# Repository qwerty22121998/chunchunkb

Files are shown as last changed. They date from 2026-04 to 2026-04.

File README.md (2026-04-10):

# CHUNCHUN

Wireless split ortholinear keyboard with 70 keys, 2 nice!view displays, 2 rotary encoders.

Original inspirated by Sofle keyboard, but I want to add more keys (F-rows) and ortholinear layout. I also want to add 2 nice!view displays and 2 rotary encoders for better user experience.

## Images

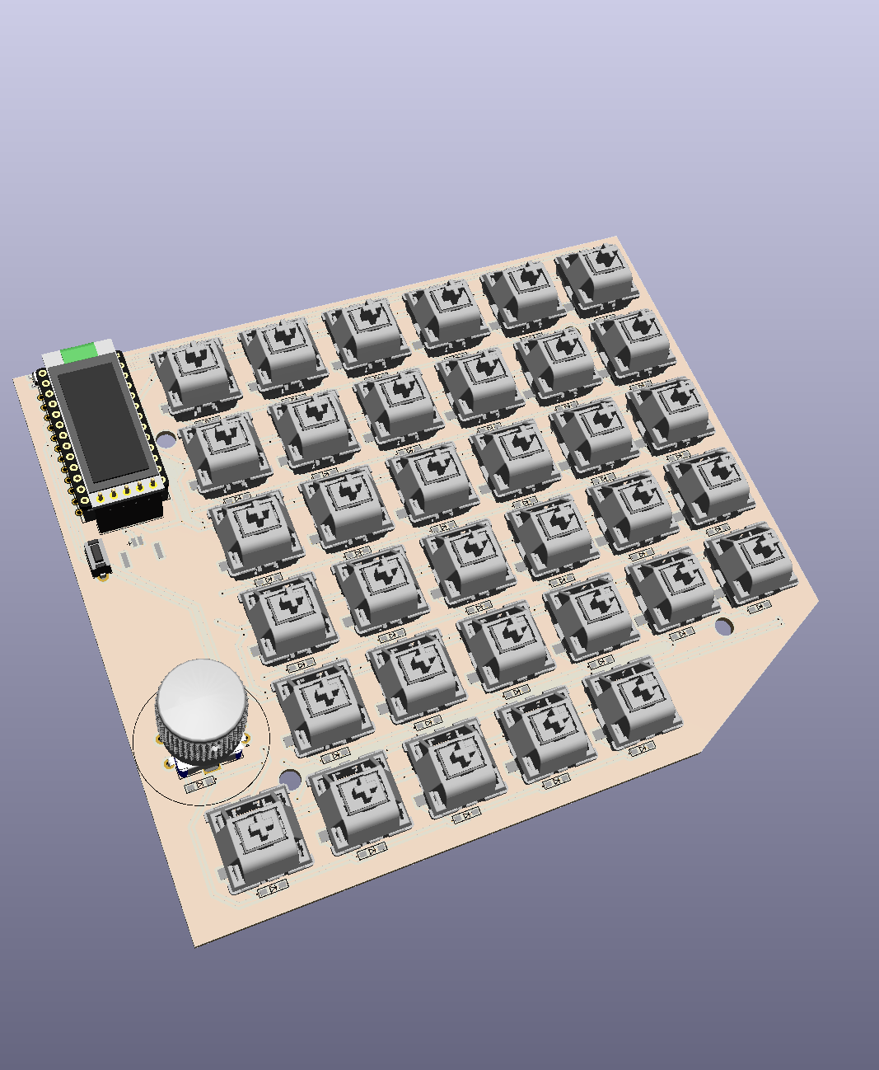
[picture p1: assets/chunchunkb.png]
Kicad rendered

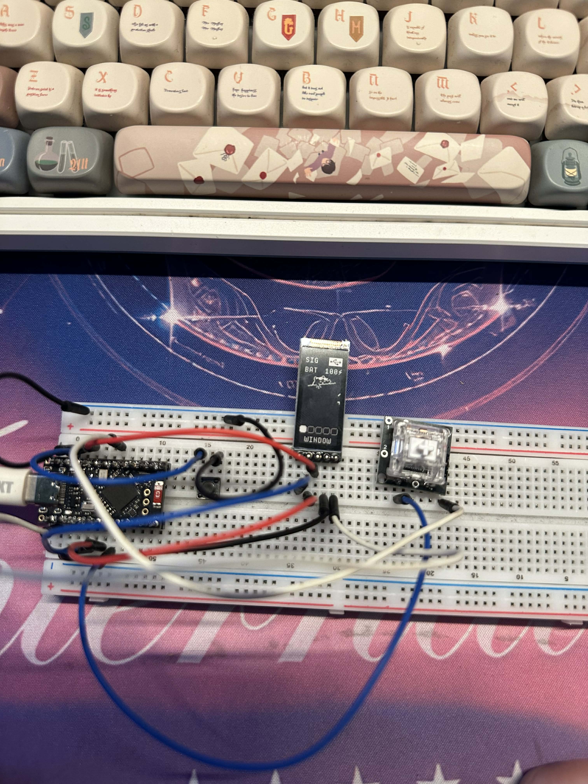
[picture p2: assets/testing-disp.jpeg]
Display testing


`TBA`

## Specifications

- 70 keys
- 2 nice!view displays (or 4pin OLED)
- 2 rotary encoders (EC11)
- Wireless connection (nice!nano or similar) with ZMK firmware support

## Firmware

[chunchunkb-zmk](https://github.com/qwerty22121998/chunchunkb-zmk)

## Bill of materials
- This only include one side of the keyboard, so you need to double the quantity for the whole keyboard.

| Value | Qty |
|---|-----|
| Nice!nano or similar | 1 |
| Nice!view or oled | 1 |
| SMD 1N4148W | 36  |
| MX Hotswap socket | 35  |
| SK6812MINI-E | 35  |
| EC11 | 1 |
| MX1.25 Ultra Thin Battery socket (or smiliar) | 1 |
| PCM12 Switch or smiliar | 1 |
| Reset switch | 1 |

### Symbols & footprints

- <https://github.com/foostan/kbd>
- <https://github.com/bstiq/nice-nano-kicad>
- <https://github.com/HookyQR/nice_view_pcb>
- <https://github.com/tzarc/reversible-kicad/>
- <https://github.com/keebio/Keebio-Parts.pretty>
- <https://github.com/josefadamcik/SofleKeyboard>

### 3D models

- <https://grabcad.com/library/dip24w-socket-with-ic-1>
- <https://grabcad.com/library/cherry-mx-1>
- <https://grabcad.com/library/mx-cherry-relegendable-keycaps-1>
- <https://grabcad.com/library/ec11-rotary-encoder-dode-switch-15mm-1>
- <https://grabcad.com/library/knobs-15>
- <https://grabcad.com/library/dsa-keycap-for-cherry-mx-switches-1>

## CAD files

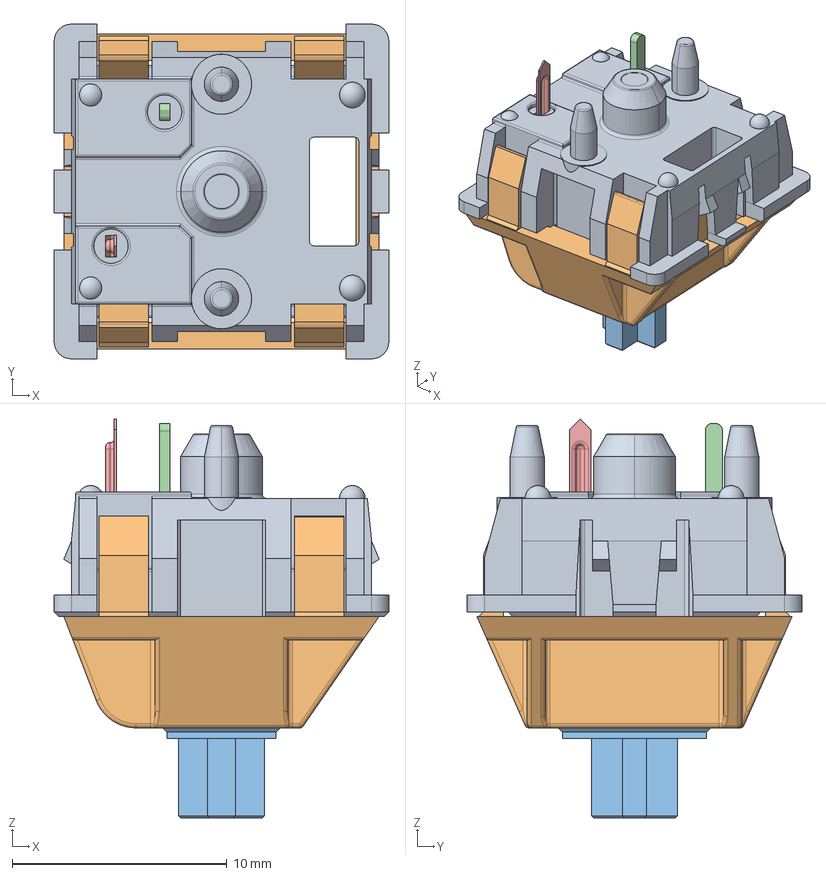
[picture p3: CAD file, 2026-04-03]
3dmodels/asm_mx_asm_PCB.stp
15.6 x 15.6 x 18.6 mm
MX_DOWN
MX_UP
UP_MX
MX_PIN
MX_SPRING
MX_CLICK

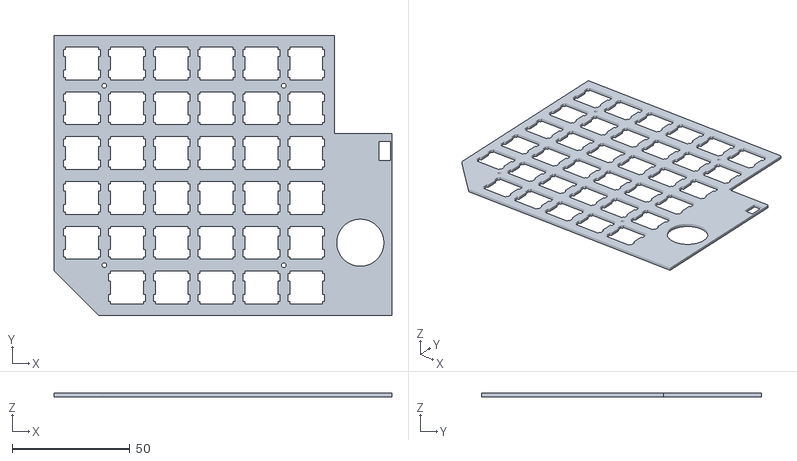
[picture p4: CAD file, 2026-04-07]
case/chunchunkb-plate.stl
143.6 x 119.1 x 1.50

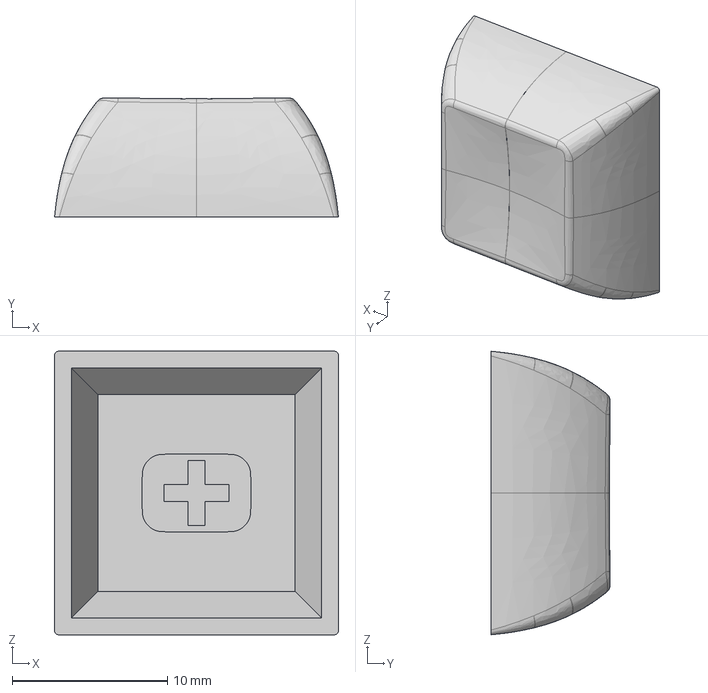
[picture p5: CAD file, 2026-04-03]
3dmodels/DSA_Keycap_CherryMX.step
18.3 x 7.69 x 18.3 mm

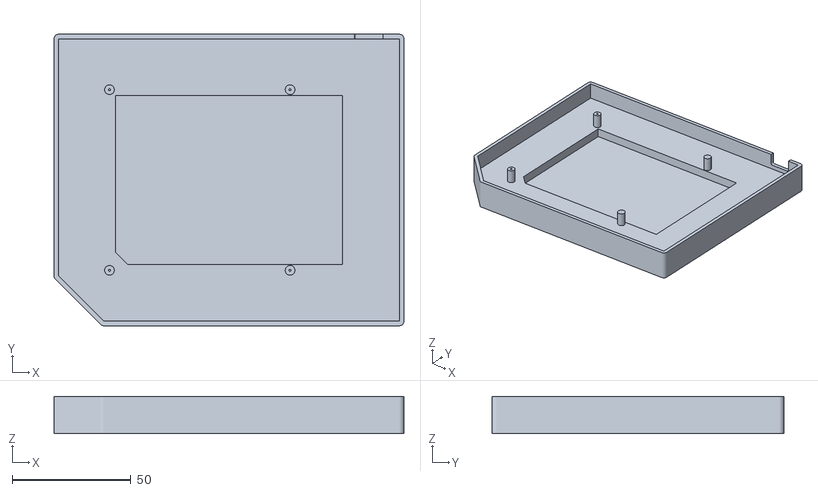
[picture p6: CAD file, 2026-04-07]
case/chunchunkb-case.stl
147.7 x 123.1 x 15.7

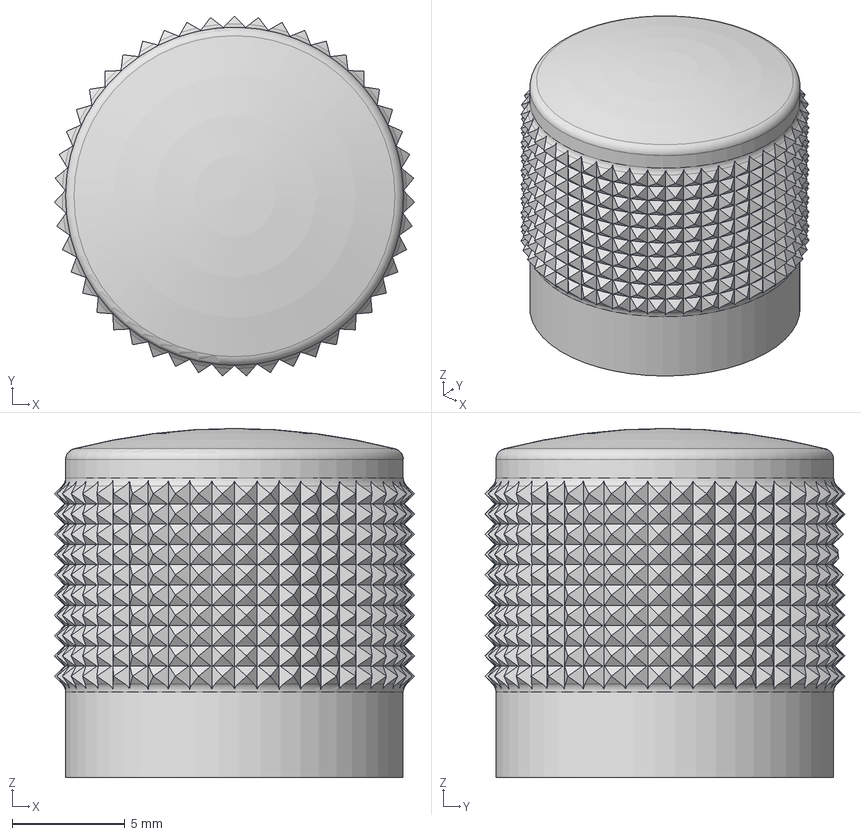
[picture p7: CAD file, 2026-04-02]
3dmodels/knobbi2.step
16.0 x 16.0 x 15.5 mm

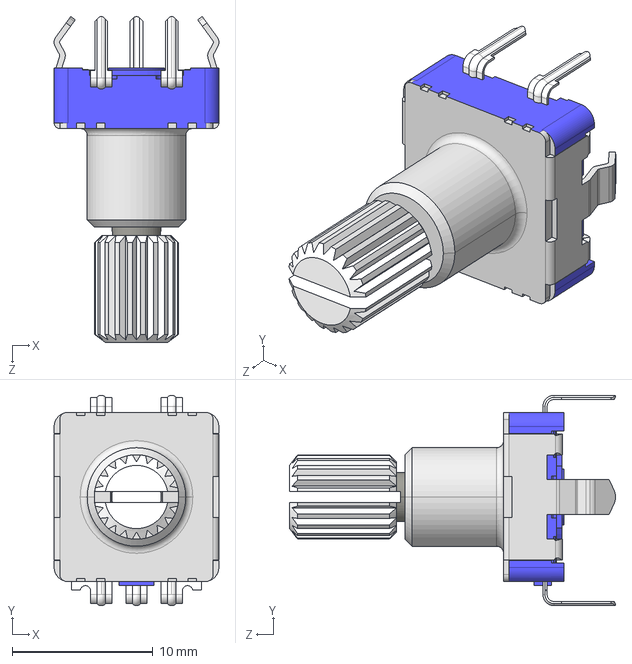
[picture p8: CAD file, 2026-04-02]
3dmodels/EC11 Rotary Encoder Dode Switch-15mm .STEP
11.7 x 15.0 x 23.2 mm

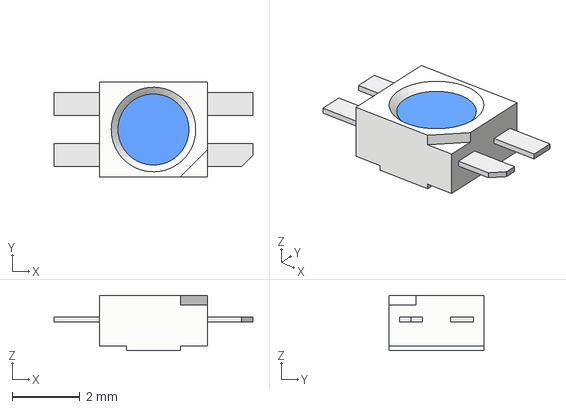
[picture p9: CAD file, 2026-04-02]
3dmodels/kbd.YS-SK6812MINI-E.step
5.88 x 2.80 x 1.63 mm

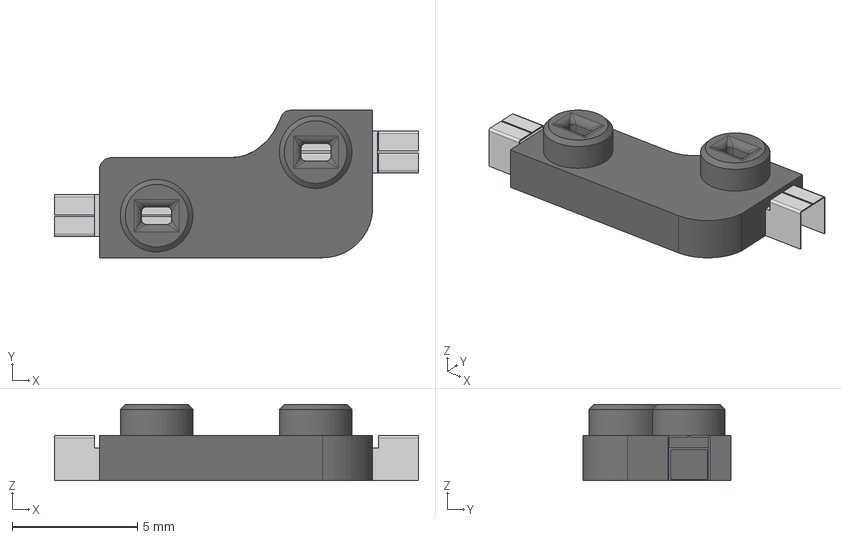
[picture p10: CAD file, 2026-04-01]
3dmodels/kbd.kailh_hotswap_socket.step
14.5 x 5.89 x 3.05 mm

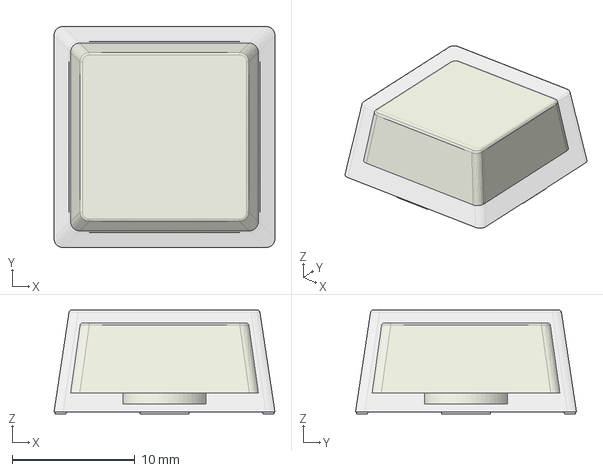
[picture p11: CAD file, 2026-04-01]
3dmodels/beschr. Kappe.step
18.0 x 18.0 x 8.45 mm
beschr. Kappe Abdeckung
beschr. Kappe Unterteil

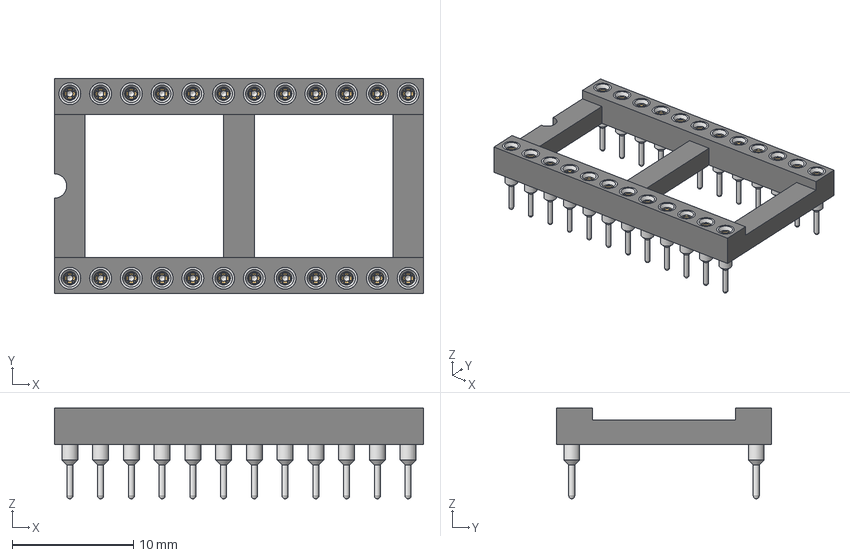
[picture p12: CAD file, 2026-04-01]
3dmodels/Socket_24_wide.stp
30.5 x 17.8 x 7.50 mm
Body24_wide
Pin_body x 24
Pin_contact x 24

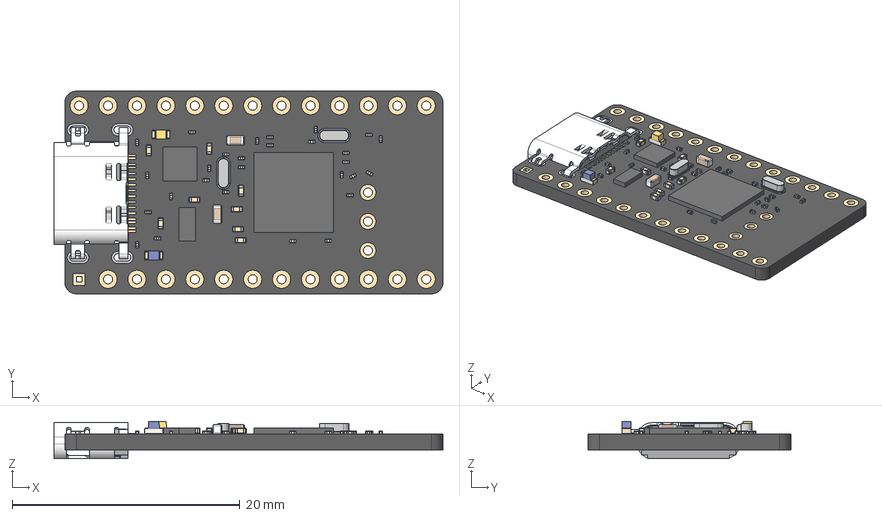
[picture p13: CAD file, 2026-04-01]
3dmodels/nice!nano v2.step
34.2 x 17.8 x 3.28 mm
nice!nano v1.0
SSOP16
LED_0603_1608Metric_ON
LED_0603_1608Metric_ON_1
Crystal Oscillator
Crystal Oscillator_1
usb4520-03-0-a_1
C0201 x 21
C0402 x 8
C0201_1 x 7

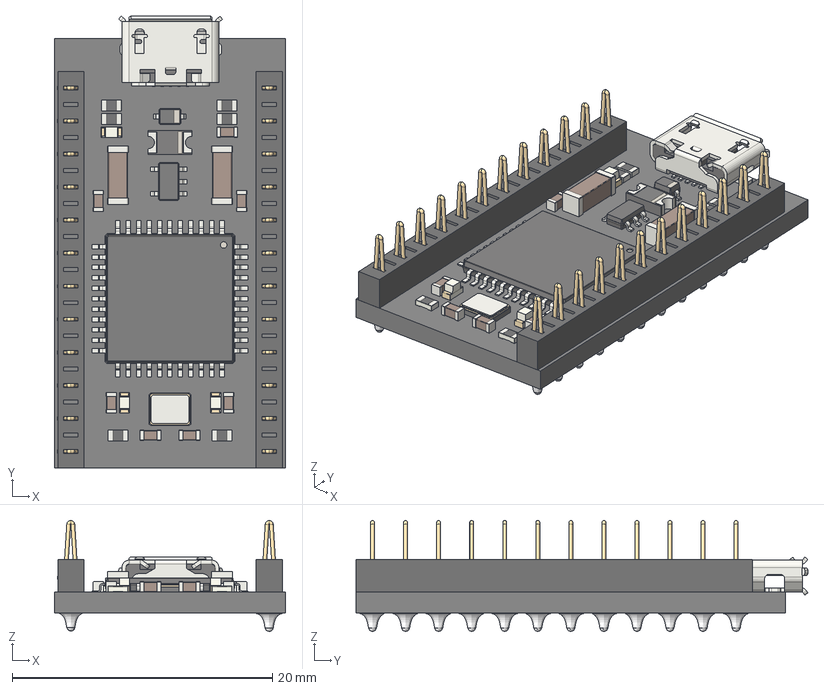
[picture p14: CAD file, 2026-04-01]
3dmodels/kbd.ProMicro.step
17.8 x 34.7 x 8.54 mm
TQFP-44_10x10mm_P0.8mm
USB_Micro-B_Molex_47346-0001
R_0603 x 6
LED_0603_1608Metric x 3
C_0603_1608Metric x 8
Crystal_SMD_3225-4Pin_3.2x2.5mm
D_SOD-323
D_1206_3216Metric
TSOT-23-5
C_1806_4516Metric x 2
conthrough x 2

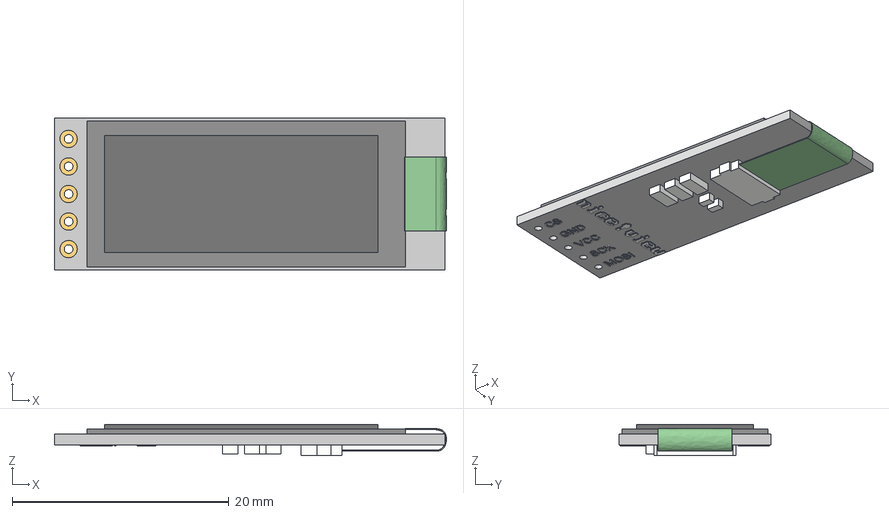
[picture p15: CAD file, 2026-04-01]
3dmodels/nice!view.step
36.1 x 14.0 x 2.90 mm

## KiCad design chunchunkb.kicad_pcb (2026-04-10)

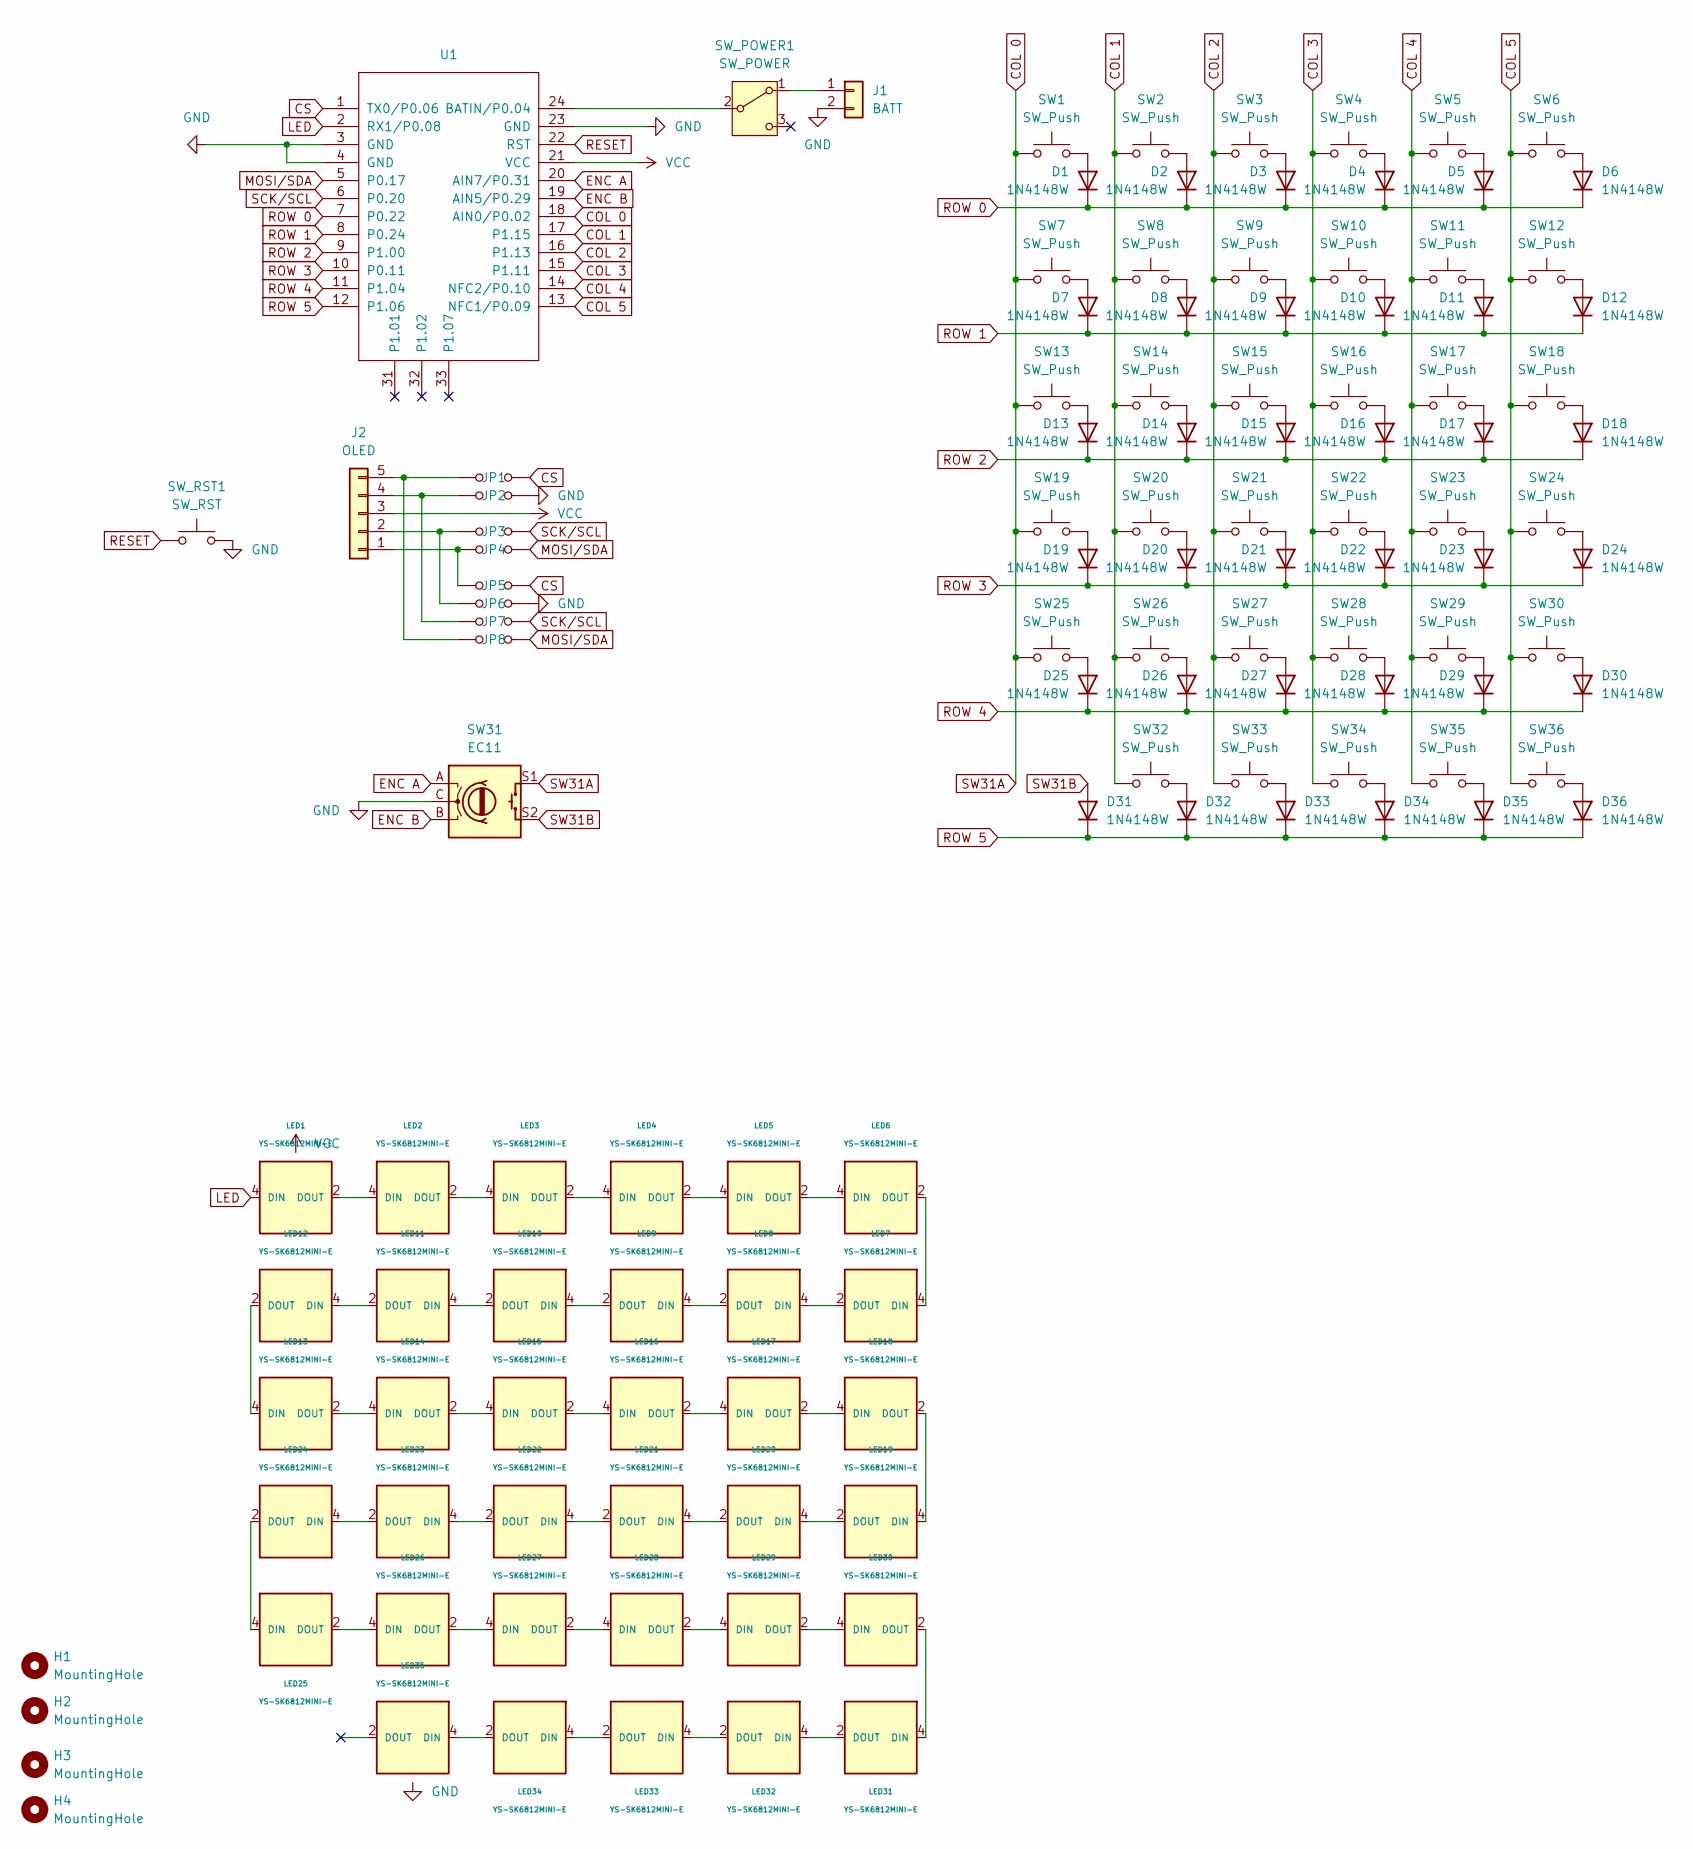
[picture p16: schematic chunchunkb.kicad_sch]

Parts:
D1, D2, D3, D4, D5, D6, D7, D8, D9, D10, D11, D12, D13, D14, D15, D16, D17, D18, D19, D20, D21, D22, D23, D24, D25, D26, D27, D28, D29, D30, D31, D32, D33, D34, D35, D36: 1N4148W; crkbd-diode
H1, H2, H3, H4: MountingHole; HOLE_M2_TH
J1: BATT; MX1.25mm
J2: OLED; nice_view
JP1, JP2, JP3, JP4, JP5, JP6, JP7, JP8: jumper; Jumper
LED1, LED2, LED3, LED4, LED5, LED6, LED7, LED8, LED9, LED10, LED11, LED12, LED13, LED14, LED15, LED16, LED17, LED18, LED19, LED20, LED21, LED22, LED23, LED24, LED25, LED26, LED27, LED28, LED29, LED30, LED31, LED32, LED33, LED34, LED35: YS-SK6812MINI-E
SW1, SW2, SW3, SW4, SW5, SW6, SW7, SW8, SW9, SW10, SW11, SW12, SW13, SW14, SW15, SW16, SW17, SW18, SW19, SW20, SW21, SW22, SW23, SW24, SW25, SW26, SW27, SW28, SW29, SW30, SW32, SW33, SW34, SW35, SW36: SW_Push; MX-1U-Hotswap
SW31: EC11; EC11_Switch
SW_POWER1: SW_POWER; SW_SPDT_PCM12
SW_RST1: SW_RST; SW_PUSH_1P1T_6x3.5mm_H4.3_APEM_MJTP1243
U1: ProMicro DUAL

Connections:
COL 0: SW1.1, SW7.1, SW13.1, SW19.1, SW25.1, SW31.S1, U1.18 (AIN0/P0.02)
COL 1: SW2.1, SW8.1, SW14.1, SW20.1, SW26.1, SW32.1, U1.17 (P1.15)
COL 2: SW3.1, SW9.1, SW15.1, SW21.1, SW27.1, SW33.1, U1.16 (P1.13)
COL 3: SW4.1, SW10.1, SW16.1, SW22.1, SW28.1, SW34.1, U1.15 (P1.11)
COL 4: SW5.1, SW11.1, SW17.1, SW23.1, SW29.1, SW35.1, U1.14 (NFC2/P0.10)
COL 5: SW6.1, SW12.1, SW18.1, SW24.1, SW30.1, SW36.1, U1.13 (NFC1/P0.09)
CS: JP1.2 (B), JP5.2 (B), U1.1 (TX0/P0.06)
ENC A: SW31.A, U1.20 (AIN7/P0.31)
ENC B: SW31.B, U1.19 (AIN5/P0.29)
GND: J1.2, JP2.2 (B), JP6.2 (B), LED1.3 (GND), LED2.3 (GND), LED3.3 (GND), LED4.3 (GND), LED5.3 (GND), LED6.3 (GND), LED7.3 (GND), LED8.3 (GND), LED9.3 (GND), LED10.3 (GND), LED11.3 (GND), LED12.3 (GND), LED13.3 (GND), LED14.3 (GND), LED15.3 (GND), LED16.3 (GND), LED17.3 (GND), LED18.3 (GND), LED19.3 (GND), LED20.3 (GND), LED21.3 (GND), LED22.3 (GND), LED23.3 (GND), LED24.3 (GND), LED25.3 (GND), LED26.3 (GND), LED27.3 (GND), LED28.3 (GND), LED29.3 (GND), LED30.3 (GND), LED31.3 (GND), LED32.3 (GND), LED33.3 (GND), LED34.3 (GND), LED35.3 (GND), SW31.C, SW_RST1.2, U1.3 (GND), U1.4 (GND), U1.23 (GND)
LED: LED1.4 (DIN), U1.2 (RX1/P0.08)
MOSI/SDA: JP4.2 (B), JP8.2 (B), U1.5 (P0.17)
unnamed: D1.2 (A), SW1.2
unnamed: D2.2 (A), SW2.2
unnamed: D3.2 (A), SW3.2
unnamed: D4.2 (A), SW4.2
unnamed: D5.2 (A), SW5.2
unnamed: D6.2 (A), SW6.2
unnamed: D7.2 (A), SW7.2
unnamed: D8.2 (A), SW8.2
unnamed: D9.2 (A), SW9.2
unnamed: D10.2 (A), SW10.2
unnamed: D11.2 (A), SW11.2
unnamed: D12.2 (A), SW12.2
unnamed: D13.2 (A), SW13.2
unnamed: D14.2 (A), SW14.2
unnamed: D15.2 (A), SW15.2
unnamed: D16.2 (A), SW16.2
unnamed: D17.2 (A), SW17.2
unnamed: D18.2 (A), SW18.2
unnamed: D19.2 (A), SW19.2
unnamed: D20.2 (A), SW20.2
unnamed: D21.2 (A), SW21.2
unnamed: D22.2 (A), SW22.2
unnamed: D23.2 (A), SW23.2
unnamed: D24.2 (A), SW24.2
unnamed: D25.2 (A), SW25.2
unnamed: D26.2 (A), SW26.2
unnamed: D27.2 (A), SW27.2
unnamed: D28.2 (A), SW28.2
unnamed: D29.2 (A), SW29.2
unnamed: D30.2 (A), SW30.2
unnamed: D32.2 (A), SW32.2
unnamed: D33.2 (A), SW33.2
unnamed: D34.2 (A), SW34.2
unnamed: D35.2 (A), SW35.2
unnamed: D36.2 (A), SW36.2
unnamed: J1.1, SW_POWER1.1 (A)
unnamed: J2.1, JP4.1 (A), JP5.1 (A)
unnamed: J2.2, JP3.1 (A), JP6.1 (A)
unnamed: J2.4, JP2.1 (A), JP7.1 (A)
unnamed: J2.5, JP1.1 (A), JP8.1 (A)
unnamed: LED1.2 (DOUT), LED2.4 (DIN)
unnamed: LED2.2 (DOUT), LED3.4 (DIN)
unnamed: LED3.2 (DOUT), LED4.4 (DIN)
unnamed: LED4.2 (DOUT), LED5.4 (DIN)
unnamed: LED5.2 (DOUT), LED6.4 (DIN)
unnamed: LED6.2 (DOUT), LED7.4 (DIN)
unnamed: LED7.2 (DOUT), LED8.4 (DIN)
unnamed: LED8.2 (DOUT), LED9.4 (DIN)
unnamed: LED9.2 (DOUT), LED10.4 (DIN)
unnamed: LED10.2 (DOUT), LED11.4 (DIN)
unnamed: LED11.2 (DOUT), LED12.4 (DIN)
unnamed: LED12.2 (DOUT), LED13.4 (DIN)
unnamed: LED13.2 (DOUT), LED14.4 (DIN)
unnamed: LED14.2 (DOUT), LED15.4 (DIN)
unnamed: LED15.2 (DOUT), LED16.4 (DIN)
unnamed: LED16.2 (DOUT), LED17.4 (DIN)
unnamed: LED17.2 (DOUT), LED18.4 (DIN)
unnamed: LED18.2 (DOUT), LED19.4 (DIN)
unnamed: LED19.2 (DOUT), LED20.4 (DIN)
unnamed: LED20.2 (DOUT), LED21.4 (DIN)
unnamed: LED21.2 (DOUT), LED22.4 (DIN)
unnamed: LED22.2 (DOUT), LED23.4 (DIN)
unnamed: LED23.2 (DOUT), LED24.4 (DIN)
unnamed: LED24.2 (DOUT), LED25.4 (DIN)
unnamed: LED25.2 (DOUT), LED26.4 (DIN)
unnamed: LED26.2 (DOUT), LED27.4 (DIN)
unnamed: LED27.2 (DOUT), LED28.4 (DIN)
unnamed: LED28.2 (DOUT), LED29.4 (DIN)
unnamed: LED29.2 (DOUT), LED30.4 (DIN)
unnamed: LED30.2 (DOUT), LED31.4 (DIN)
unnamed: LED31.2 (DOUT), LED32.4 (DIN)
unnamed: LED32.2 (DOUT), LED33.4 (DIN)
unnamed: LED33.2 (DOUT), LED34.4 (DIN)
unnamed: LED34.2 (DOUT), LED35.4 (DIN)
unnamed: SW_POWER1.2 (B), U1.24 (BATIN/P0.04)
RESET: SW_RST1.1, U1.22 (RST)
ROW 0: D1.1 (K), D2.1 (K), D3.1 (K), D4.1 (K), D5.1 (K), D6.1 (K), U1.7 (P0.22)
ROW 1: D7.1 (K), D8.1 (K), D9.1 (K), D10.1 (K), D11.1 (K), D12.1 (K), U1.8 (P0.24)
ROW 2: D13.1 (K), D14.1 (K), D15.1 (K), D16.1 (K), D17.1 (K), D18.1 (K), U1.9 (P1.00)
ROW 3: D19.1 (K), D20.1 (K), D21.1 (K), D22.1 (K), D23.1 (K), D24.1 (K), U1.10 (P0.11)
ROW 4: D25.1 (K), D26.1 (K), D27.1 (K), D28.1 (K), D29.1 (K), D30.1 (K), U1.11 (P1.04)
ROW 5: D31.1 (K), D32.1 (K), D33.1 (K), D34.1 (K), D35.1 (K), D36.1 (K), U1.12 (P1.06)
SCK/SCL: JP3.2 (B), JP7.2 (B), U1.6 (P0.20)
SW31B: D31.2 (A), SW31.S2
VCC: J2.3, LED1.1 (VDD), LED2.1 (VDD), LED3.1 (VDD), LED4.1 (VDD), LED5.1 (VDD), LED6.1 (VDD), LED7.1 (VDD), LED8.1 (VDD), LED9.1 (VDD), LED10.1 (VDD), LED11.1 (VDD), LED12.1 (VDD), LED13.1 (VDD), LED14.1 (VDD), LED15.1 (VDD), LED16.1 (VDD), LED17.1 (VDD), LED18.1 (VDD), LED19.1 (VDD), LED20.1 (VDD), LED21.1 (VDD), LED22.1 (VDD), LED23.1 (VDD), LED24.1 (VDD), LED25.1 (VDD), LED26.1 (VDD), LED27.1 (VDD), LED28.1 (VDD), LED29.1 (VDD), LED30.1 (VDD), LED31.1 (VDD), LED32.1 (VDD), LED33.1 (VDD), LED34.1 (VDD), LED35.1 (VDD), U1.21 (VCC)

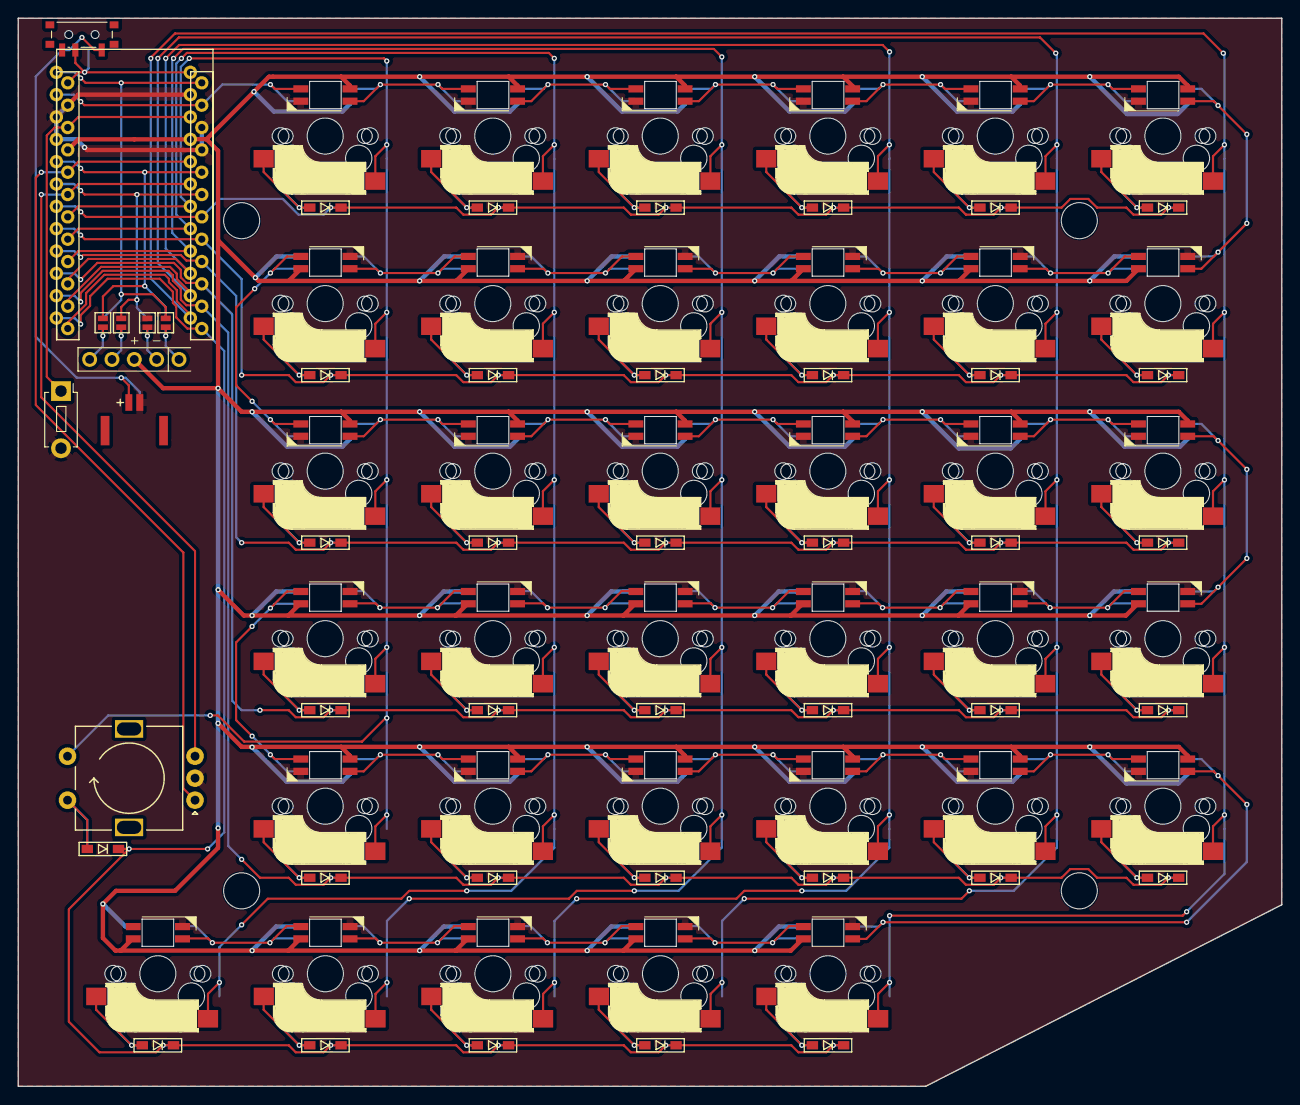
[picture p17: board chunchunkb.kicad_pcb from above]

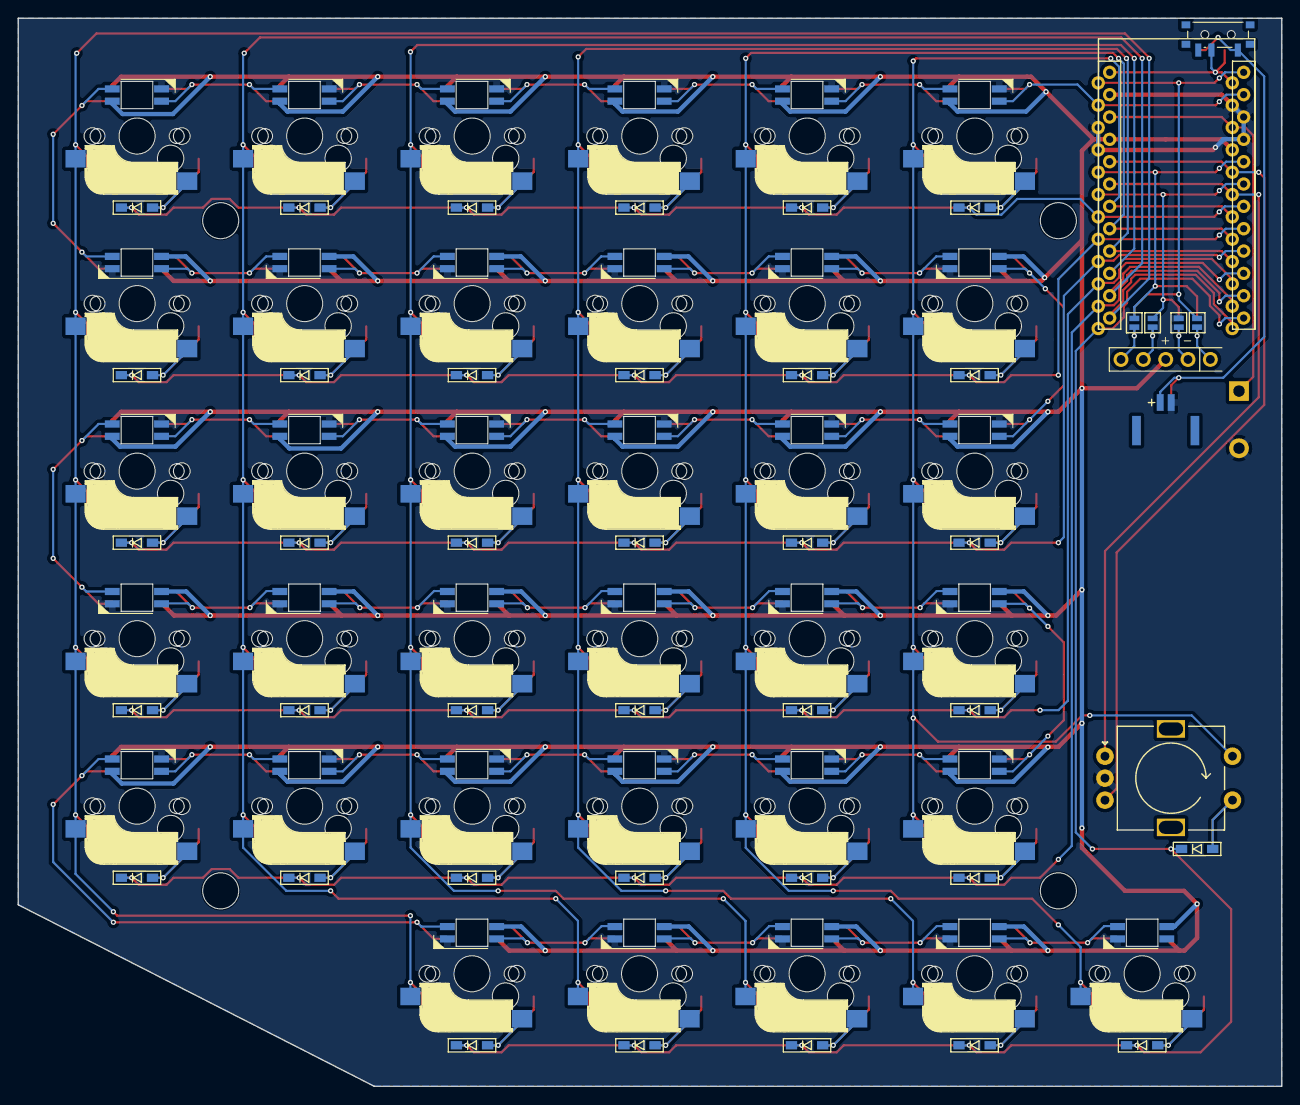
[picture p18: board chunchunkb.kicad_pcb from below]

Board: 2 copper layers, 143.7 x 121.4 mm, 124 parts (4 on the bottom side), 97 nets.

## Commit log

2026-03-30 feat: init
    [chunchunkb.kicad_pcb, chunchunkb.kicad_sch]
2026-03-30 chore: reroute
    [chunchunkb.kicad_pcb]
2026-04-01 dual pcb
    [Socket_24_wide.stp, akko wine red v5.step, beschr. Kappe.step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]
2026-04-03 feat: resize via, rerouting
    [chunchunkb.kicad_pcb, chunchunkb.kicad_sch]
2026-04-03 fix switch footprint
    [chunchunkb.kicad_pcb, chunchunkb.kicad_sch]
2026-04-03 fix 3d models
    [DSA_Keycap_CherryMX.step, akko wine red v5.step, asm_mx_asm_PCB.stp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]
2026-04-07 feat: add case
    [chunchunkb-case.stl, chunchunkb-plate.stl, chunchunkb.kicad_pcb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]
2026-04-10 feat: change space btn pos
    [chunchunkb.kicad_pcb, chunchunkb.kicad_sch]
2026-04-10 chore: wiring
    [chunchunkb.kicad_sch]
2026-10-13 Merge pull request #2 from qwerty22121998/feat/rev2
    feat: rev 2 board
2026-10-17 feat: rev 2 reversible PCB with full routing
    - Replace the old symbol libs with chunchun_rev symbols and generated
    CC_* reversible footprints (tools/gen_footprints.py), using a jumper
    scheme and a right-half pin remap so one PCB serves both halves.
    - Route the whole board: COL/ROW lanes by the nice!nano, VCC buses,
    GND fill with solid SMD connections and stitching vias.
    - Add chunchunkb.kicad_dru (45-degree bends, no same-layer T-junctions)
    and tools/check_via_bends.py for the through-via bend rule KiCad's DRC
    cannot check.
    - Diodes now put their cathodes on the ROW nets (col2row matrix).
    - Add the plate STEP export for the case.
